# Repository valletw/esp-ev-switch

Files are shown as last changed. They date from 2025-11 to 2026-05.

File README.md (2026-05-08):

# ESP Electric Vehicle charge controller

The purpose of this project is to control a EVSE (Electric Vehicle Supply
Equipment), aka. "wall-box", to charge an electric vehicle. It will open/close
the Proximity Pilot (PP), the Control Pilot (CP) and the AC coil for the main
power. This project will not managed the EV protocol and be integrated only as a
switch between the vehicle and the EVSE. The control will be done with Home
Assistant by using [ESPHome](https://esphome.io) firmware.

Custom software could be written by using ESP-IDF SDK but it is not the purpose
of this project.

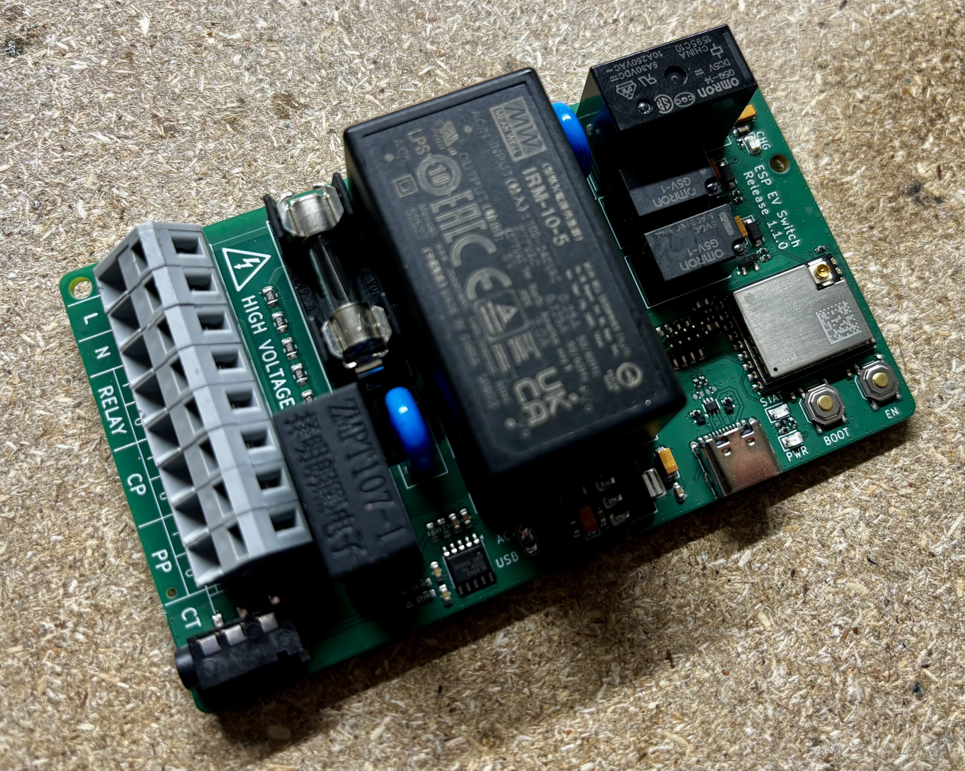
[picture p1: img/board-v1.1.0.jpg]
Board


## Signals description

**Proximity Pilot**, also known as "Plug Present", is used to signal the
connection / disconnection of the plug. It can be used to simulate a manual
disconnection by opening the circuit as the "release" button.

**Control Pilot** is used to negotiate the charge and exchange information by
the vehicle and the EVSE. In case of proximity pilot is not detected, the signal
can be opened to trigger an error on the charge controller.

**AC coil** is used to open/close the main power relay. In case of power is still
remaining after PP and CP are opened.

## Disclaimer

The authors and contributors of this repository disclaim any and all
responsibility for the misuse of the information, tools, or techniques described
herein. Users are strictly advised to utilize this information in accordance with
applicable laws and regulations and only on systems for which they have explicit
authorization.

Neither the authors nor contributors shall be held liable for any damages, direct
or indirect, resulting from the misuse or unauthorized application of the
knowledge contained herein.

These device is powered from 230V line. Every flash and debug steps shall be
take with extreme caution with main power supply disconnected or by using
an isolator on the USB connector !

## Hardware

Wago connector is used for easy plug with the different wall-box wires:

- `L`: Line (230V)
- `N`: Neutral
- `RELAY I/O`: EVSE main power supply coil control Input/Output
- `CP I/O`: EVSE Control Pilot Input/Output
- `PP I/O`: EVSE Proximity Pilot Input/Output

3.5mm jack is available for current transformer measure. It's compatible with the
sensor SCT-013-050. Different current limit could be selected depending of the
maximum voltage of your wall-box: for a 7kW charge, select at least a probe for
50 A.

Three status LED are available:

- `PWR`: 3.3V state
- `STAT`: System status controlled by software
- `CHG`: Charge indicator (all circuits are open/close)

Two buttons are available for ESP32 boot sequence:

- `BOOT`: Control processor download mode on boot
- `EN`: Control processor reset

For advanced debug, a 2x5 1.27 pins header connectors is available with the
Cortex-M JTAG/SWD pinout for external probe.

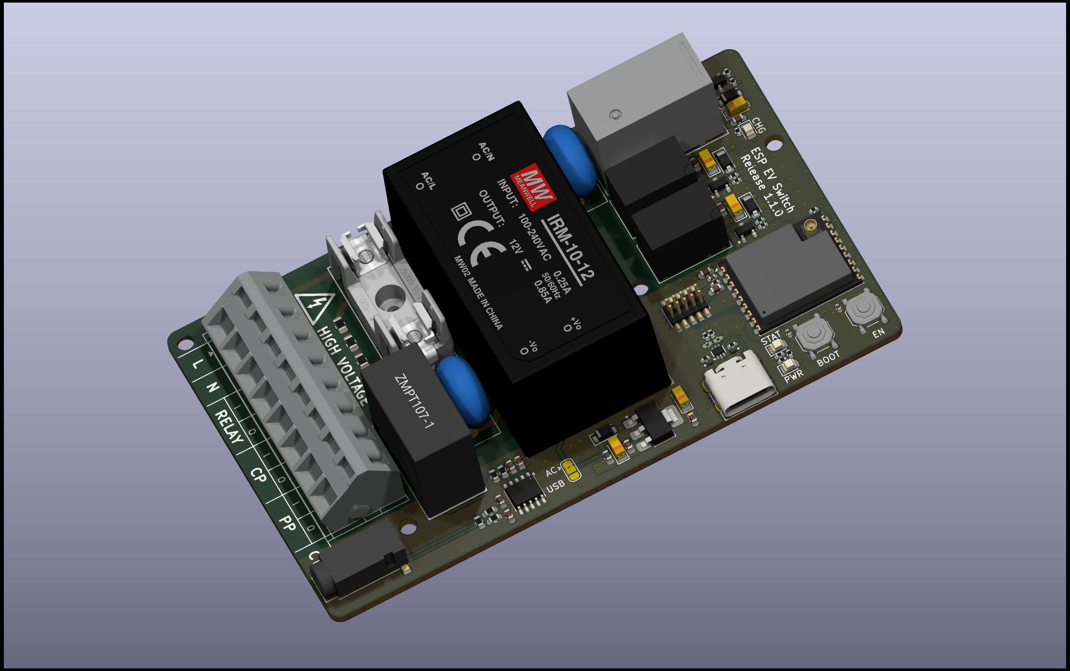
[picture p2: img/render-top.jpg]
Board top render

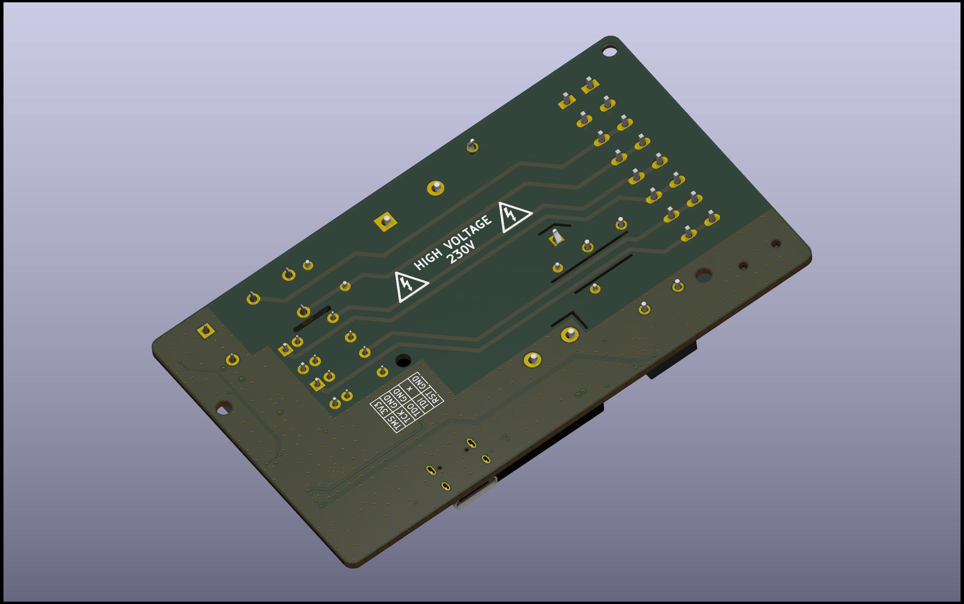
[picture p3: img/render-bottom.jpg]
Board bottom render


### Wiring

The board will be placed between the EVSE and the EV plug. It will open/close
the different signals to control the main power relay, the control signal and
the proximity signal.

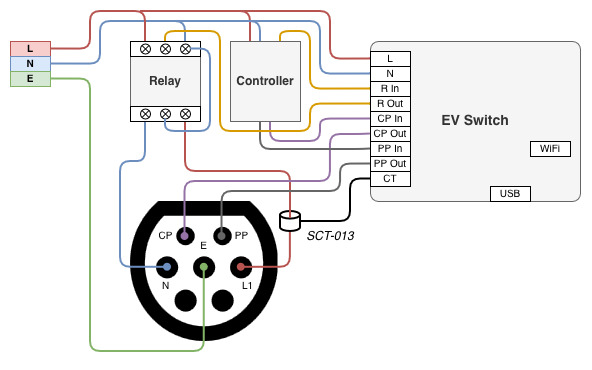
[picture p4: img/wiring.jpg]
EV Switch Wiring


Note: This wiring could be adapted for tri-phase system and should be able
to control the EVSE. The power measure can only be done on one phase.

You can see my setup on a QUBEV wallbox. The clamp take some space and I had to
put it on the input instead of the relay output because of the EV plug when I
closed the enclosure.

Also, the jack for the clamp broke when I installed the board, I was not careful
enough. As it's not through hole connector, it break easily. I added glue and a wire
as quick fix.

Setup | Home Assistant
:----:|:--------------:
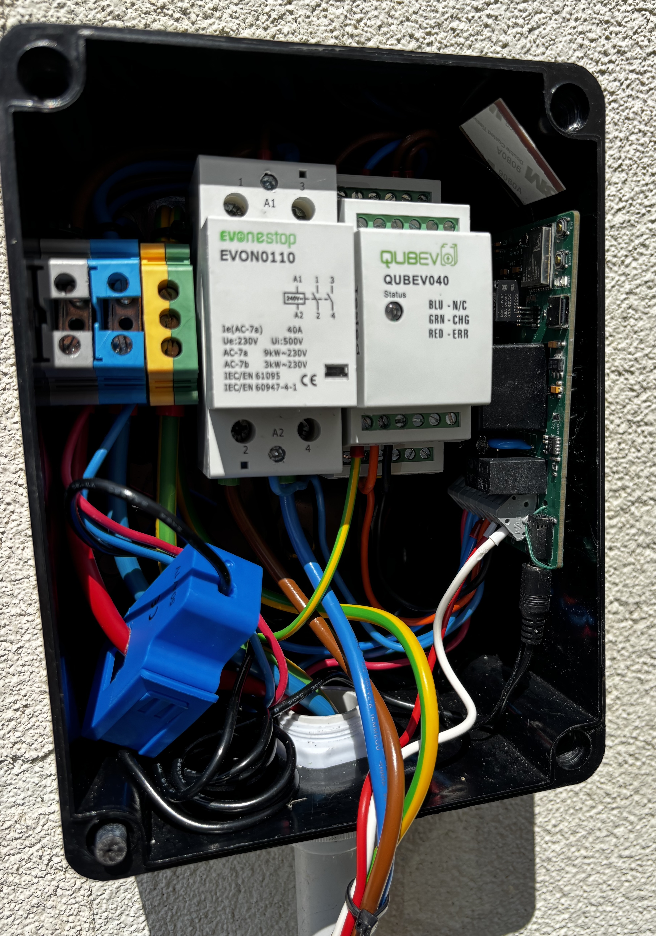
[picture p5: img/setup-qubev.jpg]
Setup on QUBEV
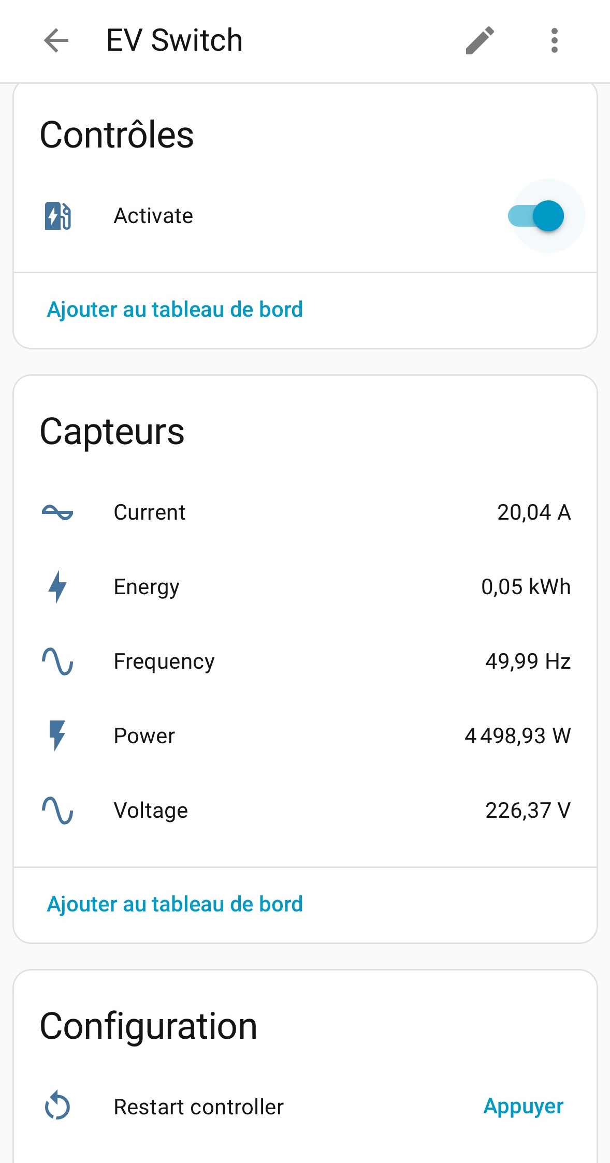
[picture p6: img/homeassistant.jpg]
Home Assistant Screenshot
 | 

Note: I limited my wallbox at 20A with an hardware switch inside.

### Components choice

This project is based on an ESP32-C3 module to simplify design and ensure good
WiFi performance (with external antenna connector). ESP32 has been selected for
the big community to generate software and the frameworks available. Espressif
hardware design rules has been take into account following there
[documentation](https://docs.espressif.com/projects/esp-hardware-design-guidelines/en/latest/esp32c3/pcb-layout-design.html)

For easy debug and flashing, ESP32 with USB-CDC and JTAG support has been selected.

The 5V power rail is generated from a Mean Well AC-DC power supply. It has been
selected for the "ready to use" and the security / certification. The 5V is used
to power the relays.
The 3.3V power rail is generated from a LDO using the 5V power rail. It's used for
the controller part: ESP32, measure and signals.

By default, the 5V from the USB connector is not connected. For debug, it can
be forced with a jumper to solder on the PCB. In this case, do not connect / solder
both 5V USB & 5V AC-DC.

All others components has been selected from [JLCPCB](https://jlcpcb.com/parts/)
catalogue to minimize the cost and the assembly fees.

### Manufacturing

The board is manufactured by [JLCPCB](https://jlcpcb.com), here is the details
you will require to generate an order.

*Note: JLCPCB requests some modifications on output files, do not use direct
export from KiCad (check the FAQ)*

#### PCB

Files: [Gerbers](jlcpcb/gerbers.zip)

Configuration              | Value
---------------------------|---------------------------------
Base Materiel              | FR-4
Layers                     | 4
Dimensions                 | 99.92 x 58.42 mm
Different design           | 1
Delivery format            | Single PCB
PCB thickness              | 1.6
PCB color                  | Green (other colors have fees)
Silkscreen                 | White
Materiel type              | FR4-Standard TG 135-140
Surface finish             | HASL
Specify layer sequence     | F_Cu / In1_Cu / In2_Cu / B_Cu
Impedance control          | Yes
Layer stack-up             | JLC04161H-7628
Via covering               | Tented
Min via hole size/diameter | 0.3mm/0.45mm
Remove order number        | Specify a location

*Note: All options have not been detail here, keep default value.*

#### Assembly

Files: [BOM](jlcpcb/bom.csv), [CPL](jlcpcb/cpl.csv)

Configuration       | Value
--------------------|--------------------
PCBA type           | Economic
Assembly side       | Top

Verify "pick & place" orientations and positions on the web viewer

*Note: All options have not been detail here, keep default value.*

### Calibration

For power consumption measurement, a BL0942 chip is used and connected to the
current transformer probe. Default values are set for the voltage, current, power
and energy reference. The BL0942 is calibration free and default value could
work. If better accuracy is required, the default value can be changed by following
a calibration process:

1. Voltage reference can be adapted by measuring the input voltage with a multimeter,
2. Current can be adapted by using a well known load: example 10 A,
3. When your voltage/current are correctly calibrated, the power can be computed
with `P = U * I`

#### Voltage reference

The voltage RMS is measured from VP/GND pins connected through a voltage transformer
for galvanic isolation. The primary side uses a resistive divider 235 kOhms (5 * 47k)
to limit the current through the transformer primary. On the secondary side, a 56 Ohms
resistor sets the output voltage, followed by a 1 kOhms series resistor on the VP pin
for protection.

The transformer is designed as a current source: the primary voltage drives a current
through R_in, which is then converted back to a voltage across R_out on the secondary:

```math
U_{out} = \frac{U_{in}}{R_{in}} \times R_{out}
```

```math
U_{out} = \frac{230}{235000} \times 56 = 54.8 mV
```

The BL0942 VP input full-scale is 70 mV RMS / 100 mV peak-to-peak. The operating
points relative to full-scale are:

Input voltage | VP voltage | % of full-scale
:------------:|:----------:|:---------------:
230 V         | 54.8 mV    | 78 %
260 V         | 61.9 mV    | 88 %

From the datasheet, the internal register value is computed with the following formula:

```math
V_{RMS} = \frac{73989 \times V(mV)}{V_{ref}}
```

```math
V_{ref} = 1.218 V
```

With the previous values (expected VP voltage and chip reference voltage) we can
estimate the voltage reference for the ESPHome configuration:

```math
Reference = \frac{V_{RMS}}{V_{in}}
```

```math
Reference = \frac{\frac{73989 \times 54.8}{1.218}}{230} = 14477
```

After test on the received board, the measured voltage reference is **14400**,
consistent with the theoretical value (< 0.5 % deviation). This value will be used
as a base to improve accuracy by adjusting it while measuring the input voltage with
a calibrated True RMS multimeter.

#### Current reference

The current RMS is measured from IP/IN pins connected to a `SCT-013-050` current
transformer clamp through a signal conditioning circuit.

##### SCT-013-050 model

The `SCT-013-050` is a voltage output clamp with a built-in burden resistor `Rb`.
It is designed as a current source with the following characteristics:

Parameter       | Value
----------------|-------------------------------
Rated input     | 50 A RMS
Rated output    | 1 V RMS
Internal burden | Rb = ~37 Ohms
Turns ratio     | N = 50 / (1V / 37 Ohms) = 1850
Sensitivity     | 20 mV/A RMS

The secondary current for a given primary current is:

```math
I_s = \frac{I_{in}}{N} = \frac{I_{in}}{1850}
```

##### Signal conditioning circuit

The IP/IN pins are connected as follows:

- 1 Ohms (`R201`) in parallel with CT_K/CT_L (external burden)
- 1 kOhms in series on each line (pin protection)

`R201` forms a parallel combination with `Rb`, reducing the effective burden:

```math
R_{burden} = \frac{Rb \times R201}{Rb + R201} = \frac{37 \times 1}{37 + 1} = 0.974 Ω
```

The differential voltage on IP/IN for a given primary current is:

```math
U_{out} = \frac{I_{in}}{N} \times R_{burden} = \frac{I_{in}}{1850} \times 0.974
```

The BL0942 IP/IN full-scale is 30 mV RMS / 42 mV peak-to-peak. The operating
points relative to full-scale are:

Primary current | IP/IN voltage | % of full-scale
:--------------:|:-------------:|:---------------:
50 A            | 26 mV         | 90 %
32 A            | 17 mV         | 57 %
16 A            | 8 mV          | 27 %
2 A             | 1 mV          | 3 %

##### Current reference calculation

From the datasheet, the internal register value is computed with the following formula:

```math
I_{RMS} = \frac{305978 \times U_{out}(mV)}{V_{ref}}
```

```math
V_{ref} = 1.218 V
```

With the previous values we can estimated the current reference for the ESPHome
configuration:

```math
Reference = \frac{I_{RMS}}{I_{in}} = \frac{305978 \times R_{burden}}{V_{ref} \times N}
```

```math
Reference = \frac{305978 \times 974}{1.218 \times 1850} = 132260
```

After test on the received board, the measured current reference is **119500**,
representing a ~10 % deviation from the theoretical value, consistent with the
combined tolerances of `Rb` (10 %), `R201` (1 %), and the BL0942 internal reference.
This value will be used as a base to improve accuracy by adjusting it while
measuring the input current with a calibrated True RMS clamp meter.

### ESP32 Pinout

For those who want to reuse this project, here is the ESP32 pinout to manage the
different input/output.

Name               | Pin  | Direction
-------------------|------|----------
Relay ON           | IO0  | Output
Control Pilot ON   | IO1  | Output
Charge LED         | IO2  | Output (strapping pin)
Proximity Pilot ON | IO3  | Output
System Status LED  | IO8  | Output (strapping pin)
BL0942 CF1         | IO10 | Input
BL0942 Tx          | RX   | Input
BL0942 Rx          | TX   | Output

## ESPHome configuration

Device must be setup via USB connection the first time to flash the customized
firmware with sensors/buttons configuration.

Once it has been configured successfully, you should fix the device IP on your
router for easier Home Assistant configuration.

Note: Installation can be bypassed if already done or you can use docker image.
Check [ESPHome documentation](https://esphome.io/guides/getting_started_command_line.html)
for more details.

### Installation

```shell
pip install esphome
# Ensure your user session has the correct permission for serial port.
sudo usermod -a -G dialout <USERNAME>
```

### Customize

Depending of your installation and network, a `secrets.yaml` file must be
create with your specific configuration.

```yaml
# secrets.yaml
wifi_ssid: MySSID
wifi_password: MyStrongPassphrase
wifi_fb_ssid: ATX Controller Fallback Hotspot
wifi_fb_password: StrongPassphrase
ota_password: MyOTAPassphrase
api_key: 32BytesBase64String
```

### Compile and flash

```shell
# Generate the firmware.
esphome compile esphome.yaml
# Flash the firmware to the ESP.
esphome run esphome.yaml
# Get logs.
esphome logs esphome.yaml
```

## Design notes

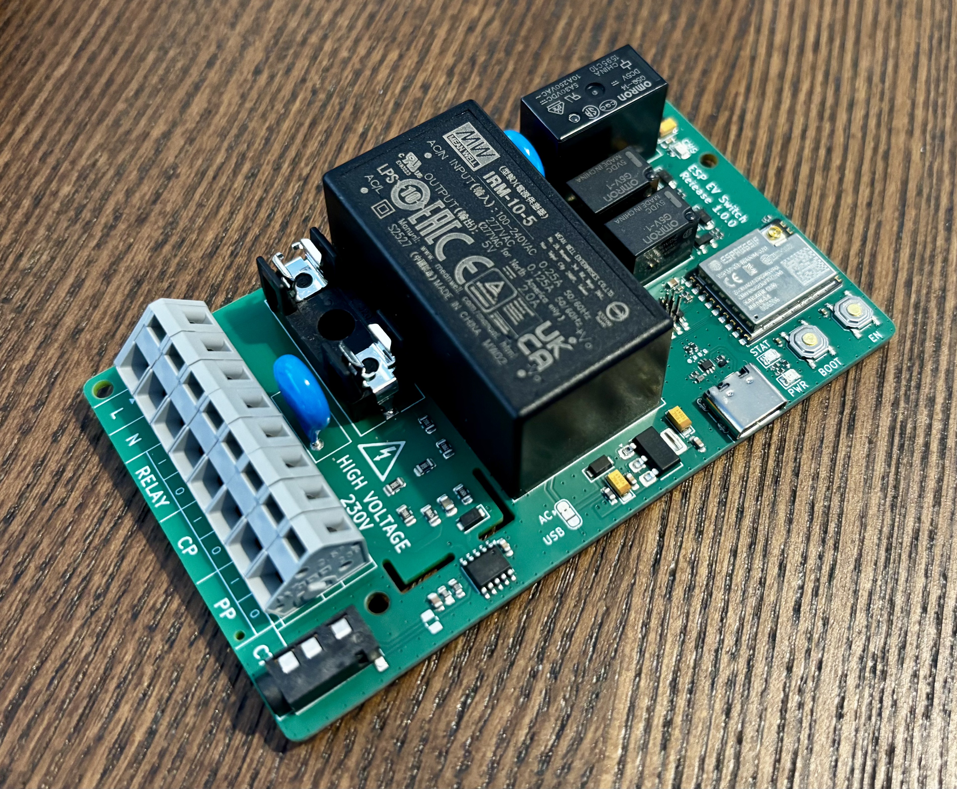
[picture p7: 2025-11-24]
img/board-v1.0.0.jpg

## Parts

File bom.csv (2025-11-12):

Reference | Value | Qty | Footprint | LCSC Part # | MFR Part # | Manufacturer | Datasheet
C101,C102,C108 | 100n | 3 | Capacitor_SMD:C_0402_1005Metric | C1525 | CL05B104KO5NNNC | Samsung Electro-Mechanics | https://datasheet.lcsc.com/lcsc/2304140030_Samsung-Electro-Mechanics-CL05B104KO5NNNC_C1525.pdf
C103,C105,C201,C204,C208 | 10u | 5 | Capacitor_Tantalum_SMD:CP_EIA-3216-18_Kemet-A | C7171 | TAJA106K016RNJ
C104,C106,C202,C205,C206,C209 | 100n | 6 | Capacitor_SMD:C_0603_1608Metric | C14663 | CC0603KRX7R9BB104 | YAGEO | https://jlcpcb.com/api/file/downloadByFileSystemAccessId/8579707083955945472
C107,C203 | 10u | 2 | Capacitor_SMD:C_0603_1608Metric | C96446 | CL10A106MA8NRNC | Samsung Electro-Mechanics | https://datasheet.lcsc.com/lcsc/2208231630_Samsung-Electro-Mechanics-CL05A106MQ5NUNC_C15525.pdf
C109 | 1u | 1 | Capacitor_SMD:C_0402_1005Metric | C52923 | CL05A105KA5NQNC | Samsung Electro-Mechanics | https://datasheet.lcsc.com/lcsc/2304140030_Samsung-Electro-Mechanics-CL05A105KA5NQNC_C52923.pdf
C110,C111 | ~ | 2 | Capacitor_SMD:C_0402_1005Metric
C207 | 100n | 1 | Capacitor_SMD:C_0805_2012Metric | C49678 | CC0805KRX7R9BB104 | YAGEO | https://jlcpcb.com/api/file/downloadByFileSystemAccessId/8579706882463744000
D101,D106 | Red | 2 | LED_SMD:LED_0805_2012Metric | C84256 | NCD0805R1 | Foshan NationStar Optoelectronics | https://jlcpcb.com/api/file/downloadByFileSystemAccessId/8550724080677908480
D102 | Green | 1 | LED_SMD:LED_0805_2012Metric | C2297 | KT-0805G | Hubei KENTO Elec | https://jlcpcb.com/api/file/downloadByFileSystemAccessId/8639582106239348736
D103,D203 | SMF5.0A | 2 | Diode_SMD:D_SOD-123F | C19077497 | SMF5.0A | hongjiacheng | https://jlcpcb.com/api/file/downloadByFileSystemAccessId/8564880887079854080
D104,D105 | TPD1E05U06 | 2 | Package_SON:Texas_DPY0002A_0.6x1mm_P0.65mm | C436349 | TPD1E05U06DPYR | Texas Instruments | https://www.ti.com/lit/ds/symlink/tpd4e05u06.pdf
D201 | 1N4007 | 1 | Diode_SMD:D_SOD-123F | C18199088 | 1N4007W | hongjiacheng | http://www.vishay.com/docs/88503/1n4001.pdf
D202,D204 | 1N4148W | 2 | Diode_SMD:D_SOD-123 | C7420318 | 1N4148W | hongjiacheng | https://jlcpcb.com/api/file/downloadByFileSystemAccessId/8590903824854953984
F101 | 5x20 250mA | 1 | footprints:Littelfuse_05200101Z | C142924 | 05200101Z | Littelfuse | https://jlcpcb.com/api/file/downloadByFileSystemAccessId/8589838583365197824
J101 | Screw_Terminal_01x08 | 1 | TerminalBlock_WAGO:TerminalBlock_WAGO_236-408_1x08_P5.00mm_45Degree | C3820284 | 236-408 | WAGO | https://jlcpcb.com/api/file/downloadByFileSystemAccessId/8590242270546337792
J102 | AudioJack3 | 1 | Connector_Audio:Jack_3.5mm_PJ320D_Horizontal | C431535 | PJ-320D | SHOU HAN | https://jlcpcb.com/api/file/downloadByFileSystemAccessId/8588894189044314112
J103 | GT-USB-7010ASV | 1 | Connector_USB:USB_C_Receptacle_G-Switch_GT-USB-7010ASV | C2988369 | GT-USB-7010ASV | G-Switch | https://datasheet.lcsc.com/lcsc/2303271630_G-Switch-GT-USB-7010ASV_C2988369.pdf
J104 | Conn_ARM_JTAG_SWD_10 | 1 | Connector_PinHeader_1.27mm:PinHeader_2x05_P1.27mm_Vertical_SMD | C41376037 | HX PZ1.27-2x5P TP | hanxia | http://infocenter.arm.com/help/topic/com.arm.doc.ddi0314h/DDI0314H_coresight_components_trm.pdf
JP101 | SolderJumper_3_Bridged12 | 1 | Jumper:SolderJumper-3_P1.3mm_Bridged2Bar12_RoundedPad1.0x1.5mm |  |  |  | ~
K201 | G5Q-14 | 1 | Relay_THT:Relay_SPDT_Omron-G5Q-1 | C397241 | G5Q-14 DC5 | Omron Electronics | https://www.omron.com/ecb/products/pdf/en-g5q.pdf
K202,K203 | G5V-1 | 2 | Relay_THT:Relay_SPDT_Omron_G5V-1 | C28695 | G5V-1 DC5 | Omron Electronics | http://omronfs.omron.com/en_US/ecb/products/pdf/en-g5v_1.pdf
L101 | Ferrite Bead | 1 | Inductor_SMD:L_0603_1608Metric | C14709 | BLM18PG121SN1D | Murata Electronics | https://jlcpcb.com/api/file/downloadByFileSystemAccessId/8588900229559300096
MH101,MH102,MH103,MH104 | ~ | 4 | MountingHole:MountingHole_2.7mm_M2.5_ISO7380 |  |  |  | ~
PS101 | IRM-10-5 | 1 | Converter_ACDC:Converter_ACDC_MeanWell_IRM-10-xx_THT | C2857903 | IRM-10-5 | MW(MEAN WELL Enterprises) | https://www.meanwell.com/Upload/PDF/IRM-10/IRM-10-SPEC.PDF
Q201,Q202,Q203 | SS8050 | 3 | Package_TO_SOT_SMD:SOT-23 | C2150 | SS8050(RANGE:200-350) | Jiangsu Changjing Electronics Technology Co., Ltd. | http://www.secosgmbh.com/datasheet/products/SSMPTransistor/SOT-23/SS8050.pdf
R101,R102,R110 | 1.2k | 3 | Resistor_SMD:R_0402_1005Metric | C25862 | 0402WGF1201TCE | UNI-ROYAL(Uniroyal Elec) | https://jlcpcb.com/api/file/downloadByFileSystemAccessId/8579706055238078464
R103,R106,R107 | 10k | 3 | Resistor_SMD:R_0402_1005Metric | C25744 | 0402WGF1002TCE | UNI-ROYAL(Uniroyal Elec) | https://datasheet.lcsc.com/lcsc/2206010100_UNI-ROYAL-Uniroyal-Elec-0402WGF1002TCE_C25744.pdf
R104,R105 | 5.1k | 2 | Resistor_SMD:R_0402_1005Metric | C25905 | 0402WGF5101TCE | UNI-ROYAL(Uniroyal Elec) | https://datasheet.lcsc.com/lcsc/2206010045_UNI-ROYAL-Uniroyal-Elec-0402WGF5101TCE_C25905.pdf
R108,R109 | 22 | 2 | Resistor_SMD:R_0402_1005Metric | C25092 | 0402WGF220JTCE | UNI-ROYAL(Uniroyal Elec) | https://jlcpcb.com/api/file/downloadByFileSystemAccessId/8579705904671227904
R201 | 33 | 1 | Resistor_SMD:R_0805_2012Metric | C17634 | 0805W8F330JT5E | UNI-ROYAL(Uniroyal Elec) | https://jlcpcb.com/api/file/downloadByFileSystemAccessId/8579706226143518720
R202,R204 | 100k | 2 | Resistor_SMD:R_0603_1608Metric | C25803 | 0603WAF1003T5E | UNI-ROYAL(Uniroyal Elec) | https://jlcpcb.com/api/file/downloadByFileSystemAccessId/8579706350726930432
R203,R209,R215 | 330 | 3 | Resistor_SMD:R_0402_1005Metric | C25104 | 0402WGF3300TCE | UNI-ROYAL(Uniroyal Elec) | https://jlcpcb.com/api/file/downloadByFileSystemAccessId/8579706350726930432
R205,R210,R216 | 100k | 3 | Resistor_SMD:R_0402_1005Metric | C25741 | 0402WGF1003TCE | UNI-ROYAL(Uniroyal Elec) | https://jlcpcb.com/api/file/downloadByFileSystemAccessId/8579706350726930432
R206,R207,R208,R211,R212 | 200k | 5 | Resistor_SMD:R_0805_2012Metric | C17539 | 0805W8F2003T5E | UNI-ROYAL(Uniroyal Elec) | https://jlcpcb.com/api/file/downloadByFileSystemAccessId/8579706517206974464
R213 | 1k | 1 | Resistor_SMD:R_0805_2012Metric | C17513 | 0805W8F1001T5E | UNI-ROYAL(Uniroyal Elec) | https://jlcpcb.com/api/file/downloadByFileSystemAccessId/8579706499683172352
R214 | 470 | 1 | Resistor_SMD:R_0805_2012Metric | C17710 | 0805W8F4700T5E | UNI-ROYAL(Uniroyal Elec) | https://jlcpcb.com/api/file/downloadByFileSystemAccessId/8579706597980880896
RV101,RV201 | 275VAC | 2 | Varistor:RV_Disc_D12mm_W5.4mm_P7.5mm | C8760 | 10D471K | RUILON(Shenzhen Ruilongyuan Elec) | https://jlcpcb.com/api/file/downloadByFileSystemAccessId/8588887227166298112
SW101,SW102 | TS-1187A-B-A-B | 2 | Button_Switch_SMD:SW_Push_1P1T_XKB_TS-1187A | C318884 | TS-1187A-B-A-B | XKB Connectivity | https://datasheet.lcsc.com/lcsc/2304140030_XKB-Connectivity-TS-1187A-B-A-B_C318884.pdf
U101 | AMS1117-3.3 | 1 | Package_TO_SOT_SMD:SOT-223-3_TabPin2 | C6186 | AMS1117-3.3 | Advanced Monolithic Systems | http://www.advanced-monolithic.com/pdf/ds1117.pdf
U102 | USBLC6-2P6 | 1 | Package_TO_SOT_SMD:SOT-666 | C15999 | USBLC6-2P6 | STMicroeletronics | https://www.st.com/resource/en/datasheet/usblc6-2.pdf
U103 | ESP32-C3-WROOM-02U | 1 | RF_Module:ESP32-C3-WROOM-02U | C2926676 | ESP32-C3-WROOM-02U-N4 | Espressif Systems | https://www.espressif.com/sites/default/files/documentation/esp32-c3-wroom-02_datasheet_en.pdf
U201 | BL0942 | 1 | Package_SO:SSOP-10_3.9x4.9mm_P1.00mm | C2837510 | BL0942 | Belling | https://www.belling.com.cn/media/file_object/bel_product_en/BL0942/datasheet/BL0942_V1.04_en.pdf

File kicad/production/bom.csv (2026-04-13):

Designator | Footprint | Quantity | Value | LCSC Part #
C101, C102, C108 | 0402 | 3 | 100n | C1525
C103, C105, C201, C204, C208 | CP_EIA-3216-18_Kemet-A | 5 | 10u | C7171
C104, C106, C202, C205, C206, C209 | 0603 | 6 | 100n | C14663
C107, C109 | 0603 | 2 | 10u | C96446
C203, C207, C210 | 0603 | 3 | 33n | C21117
D101, D106 | 0805 | 2 | Red | C84256
D102 | 0805 | 1 | Green | C2297
D103 | D_SOD-123F | 1 | SMF5.0A | C19077497
D104, D105 | Texas_DPY0002A_0.6x1mm_P0.65mm | 2 | TPD1E05U06 | C436349
D201 | D_SOD-123F | 1 | 1N4007 | C18199088
D202, D204 | D_SOD-123 | 2 | 1N4148W | C7420318
F101 | Littelfuse_05200101Z | 1 | 5x20 250mA | C142924
J101 | TerminalBlock_WAGO_236-408_1x08_P5.00mm_45Degree | 1 | Screw_Terminal_01x08 | C3820284
J102 | Jack_3.5mm_PJ320D_Horizontal | 1 | AudioJack3 | C431535
J103 | USB_C_Receptacle_G-Switch_GT-USB-7010ASV | 1 | GT-USB-7010ASV | C2988369
J104 | PinHeader_2x05_P1.27mm_Vertical_SMD | 1 | Conn_ARM_JTAG_SWD_10 | C41376037
K201 | Relay_SPDT_Omron-G5Q-1 | 1 | G5Q-14 | C397241
K202, K203 | Relay_SPDT_Omron_G5V-1 | 2 | G5V-1 | C28695
L101 | 0603 | 1 | Ferrite Bead | C14709
PS101 | Converter_ACDC_MeanWell_IRM-10-xx_THT | 1 | IRM-10-5 | C2857903
Q201, Q202, Q203 | SOT-23 | 3 | SS8050 | C2150
R101, R102, R110 | 0402 | 3 | 1.2k | C25862
R103, R106, R107 | 0402 | 3 | 10k | C25744
R104, R105 | 0402 | 2 | 5.1k | C25905
R108, R109 | 0402 | 2 | 22 | C25092
R201 | 0603 | 1 | 1 | C22936
R202, R204, R213 | 0603 | 3 | 1k | C21190
R203, R209, R215 | 0402 | 3 | 330 | C25104
R205, R210, R216 | 0402 | 3 | 100k | C25741
R206, R207, R208, R211, R212 | 0805 | 5 | 47k | C17713
R214 | 0603 | 1 | 56 | C25196
RV101, RV201 | RV_Disc_D12mm_W5.4mm_P7.5mm | 2 | 275VAC | C8760
SW101, SW102 | SW_Push_1P1T_XKB_TS-1187A | 2 | TS-1187A-B-A-B | C318884
TR201 | XFMR-TH_ZMPT107-1 | 1 | ZMPT107-1 | C125191
U101 | SOT-223-3_TabPin2 | 1 | AMS1117-3.3 | C6186
U102 | SOT-666 | 1 | USBLC6-2P6 | C15999
U103 | ESP32-C3-WROOM-02U | 1 | ESP32-C3-WROOM-02U | C2926676
U201 | SSOP-10_3.9x4.9mm_P1.00mm | 1 | BL0942 | C2837510

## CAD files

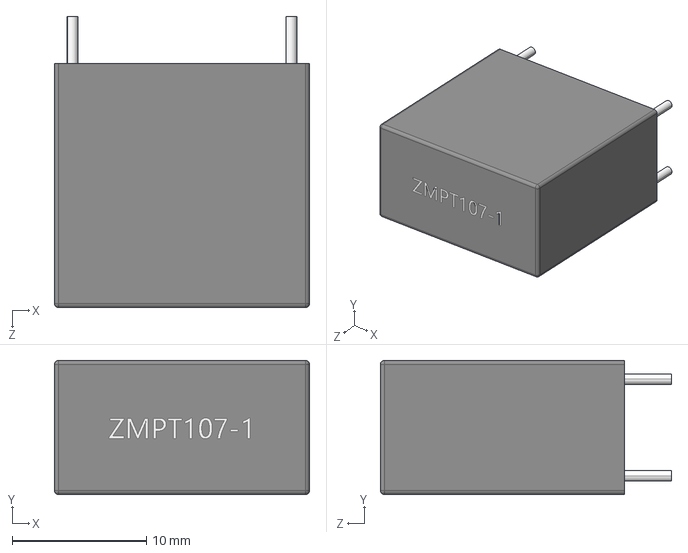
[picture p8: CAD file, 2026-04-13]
librairies/3dmodels/XFMR-TH_L19.0-W10.0-H18.2.step
19.0 x 10.0 x 21.7 mm

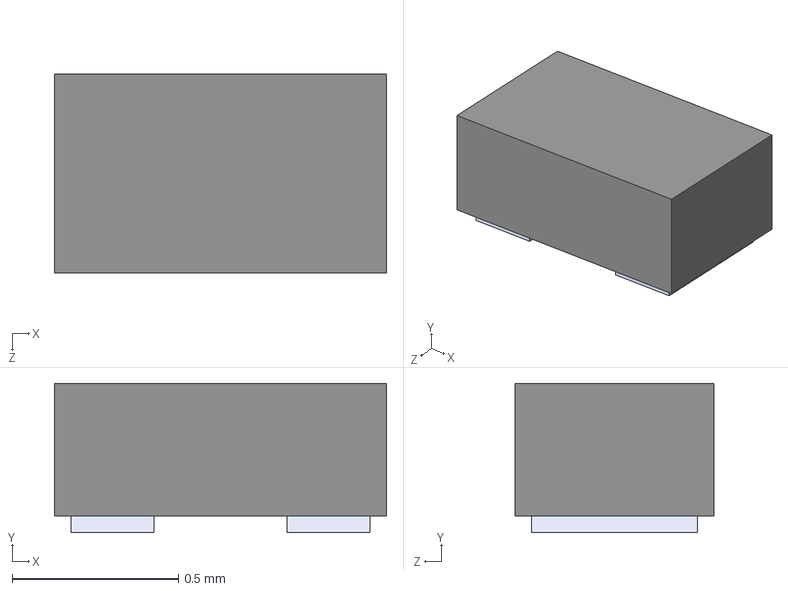
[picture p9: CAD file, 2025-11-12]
librairies/3dmodels/TPD1E05U06DPYR.step
1.00 x 0.45 x 0.6 mm

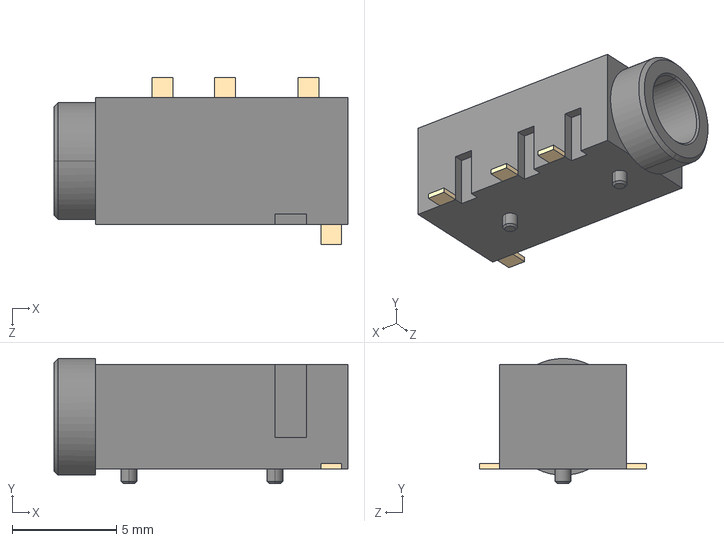
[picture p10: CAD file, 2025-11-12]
librairies/3dmodels/PJ-320D-A.step
14.1 x 6.00 x 8.00 mm

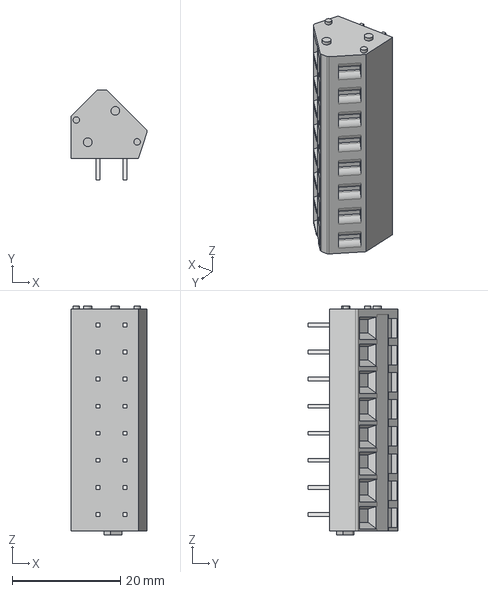
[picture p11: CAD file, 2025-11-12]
librairies/3dmodels/WAGO_236-408.stp
14.1 x 16.7 x 42.3 mm

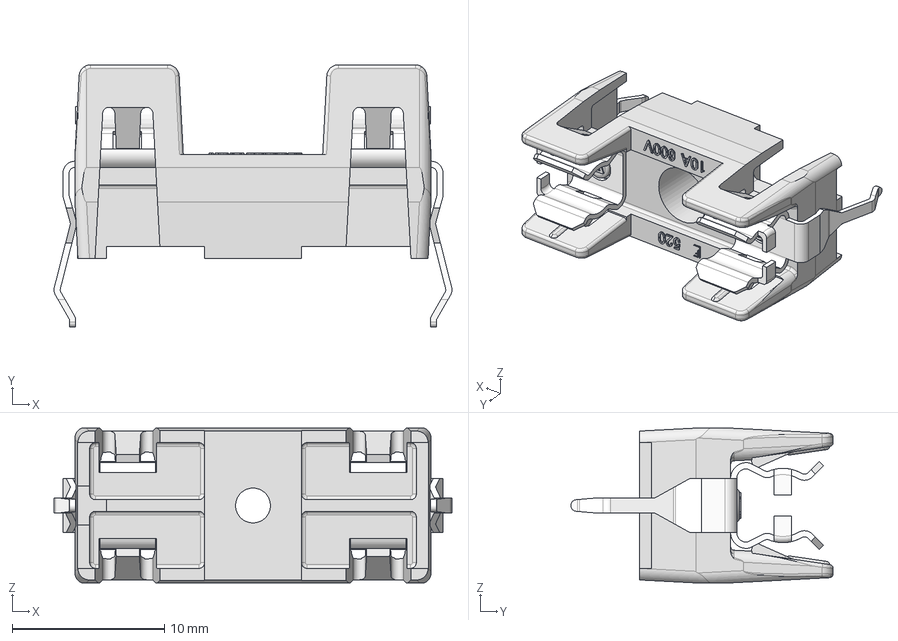
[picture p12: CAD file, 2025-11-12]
librairies/3dmodels/Littelfuse_05200101Z.stp
26.1 x 17.2 x 10.2 mm
111509_MIR

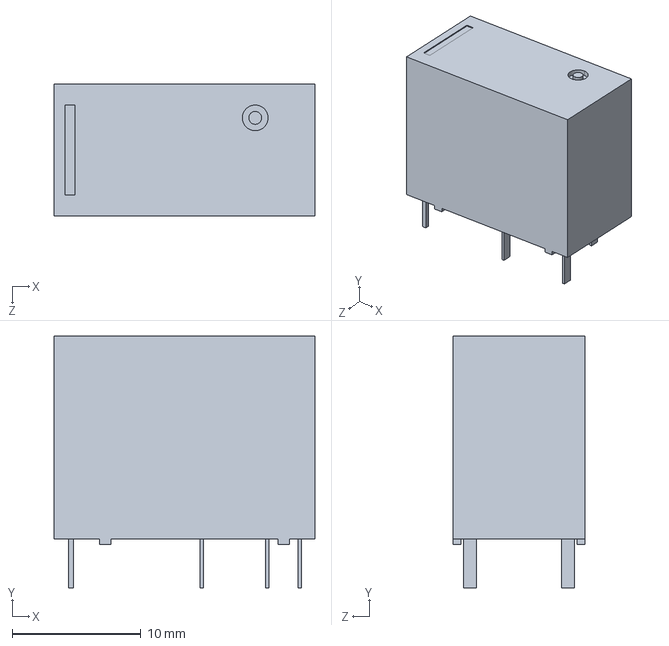
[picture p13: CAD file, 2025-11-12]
librairies/3dmodels/G5Q-14_DC5.step
20.3 x 19.6 x 10.3 mm

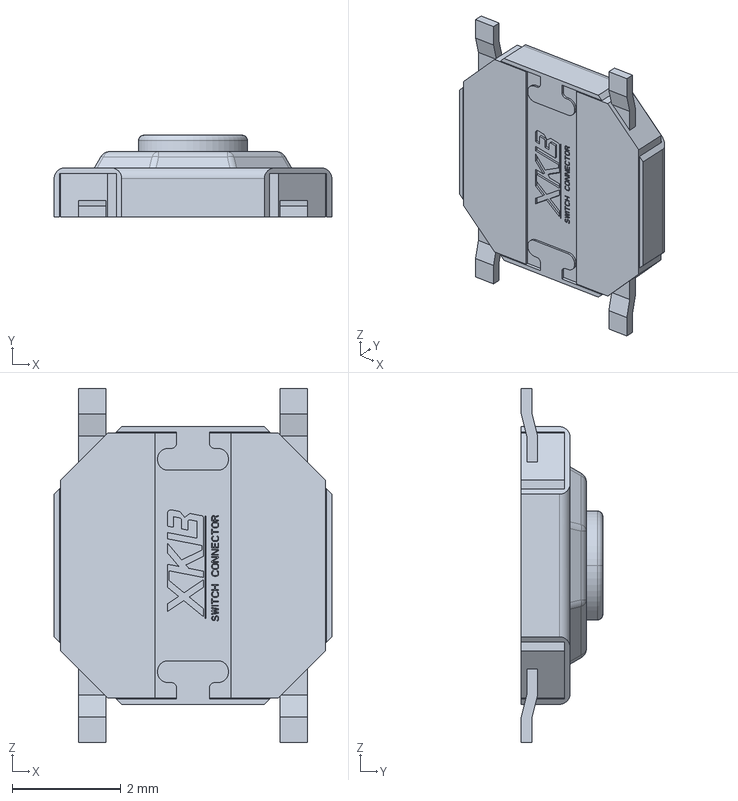
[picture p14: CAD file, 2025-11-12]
librairies/3dmodels/TS-1187A-B-A-B.stp
5.10 x 1.50 x 6.50 mm

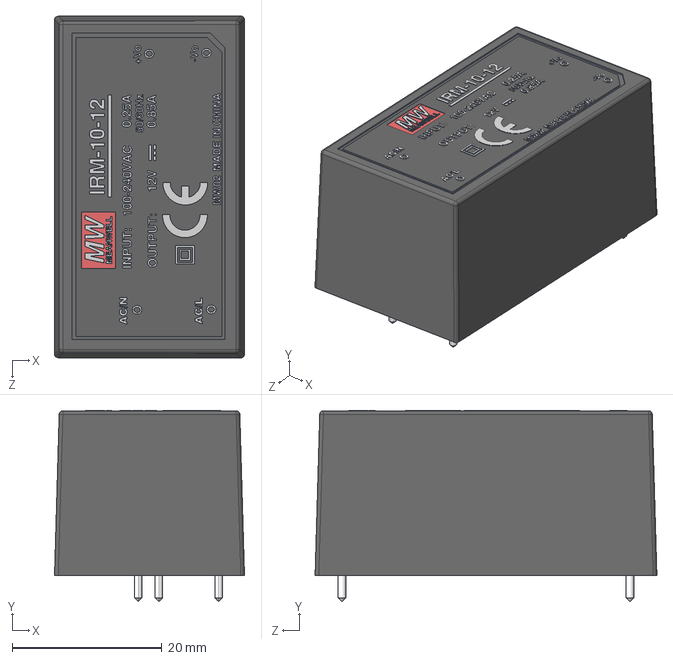
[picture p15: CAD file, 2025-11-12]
librairies/3dmodels/IRM-10-5.stp
25.4 x 25.6 x 45.7 mm

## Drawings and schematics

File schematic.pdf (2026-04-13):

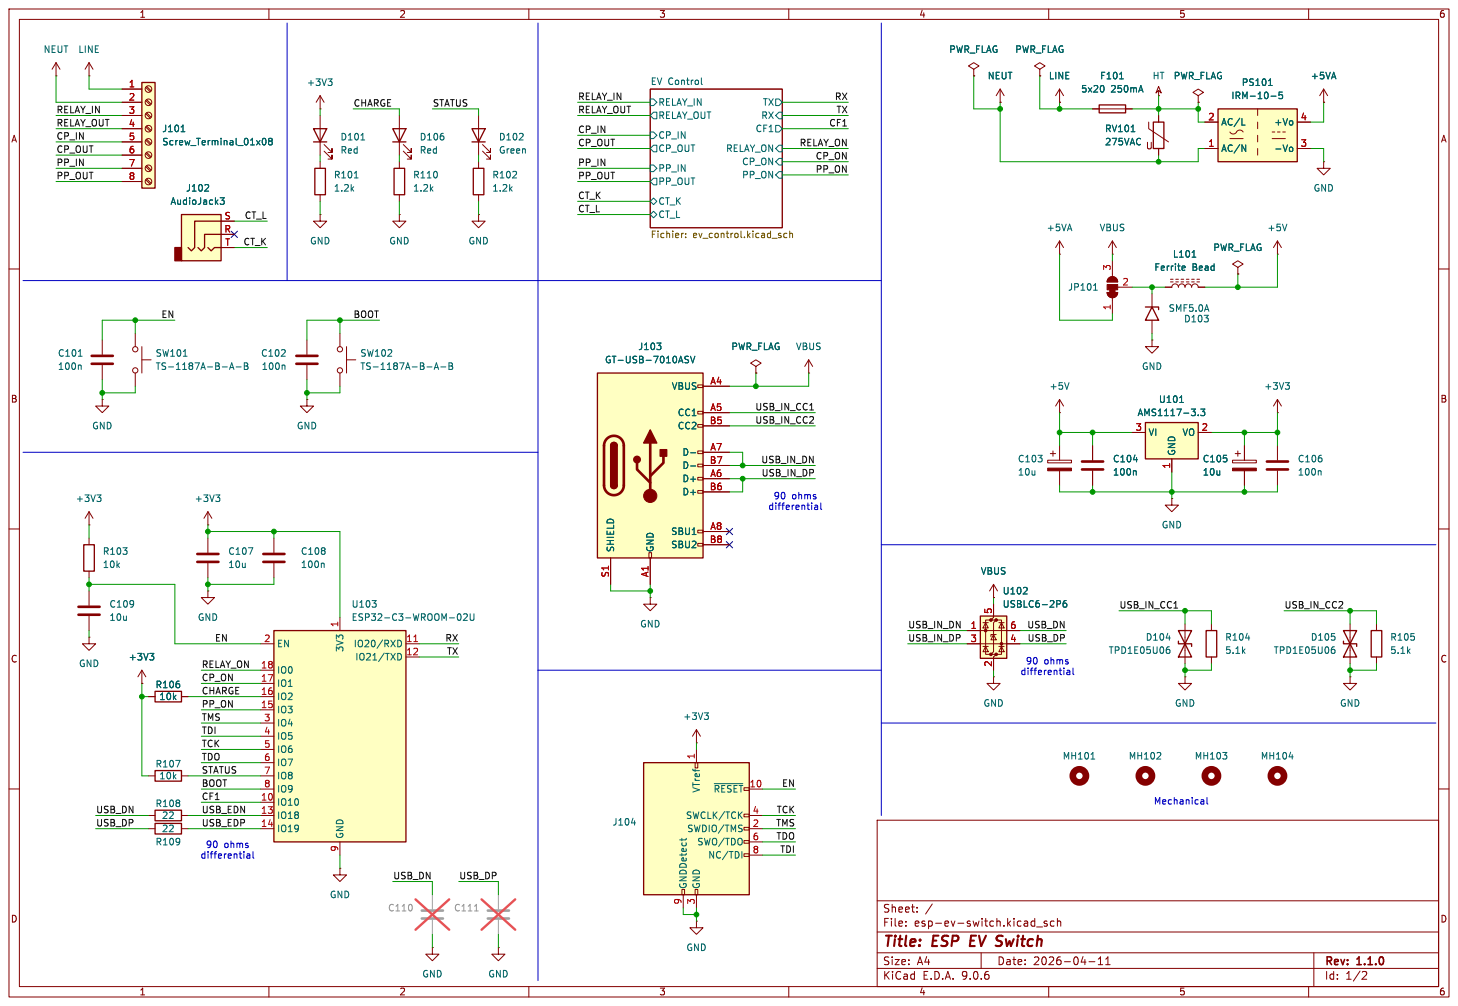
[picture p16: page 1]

3 ~{RESET}10 SWCLK/TCK 4 SWDIO/TMS 2 SWO/TDO 6 NC/TDI 8

File: esp-ev-switch.kicad_sch Sheet: /
Id: 1/2 Title: ESP EV Switch

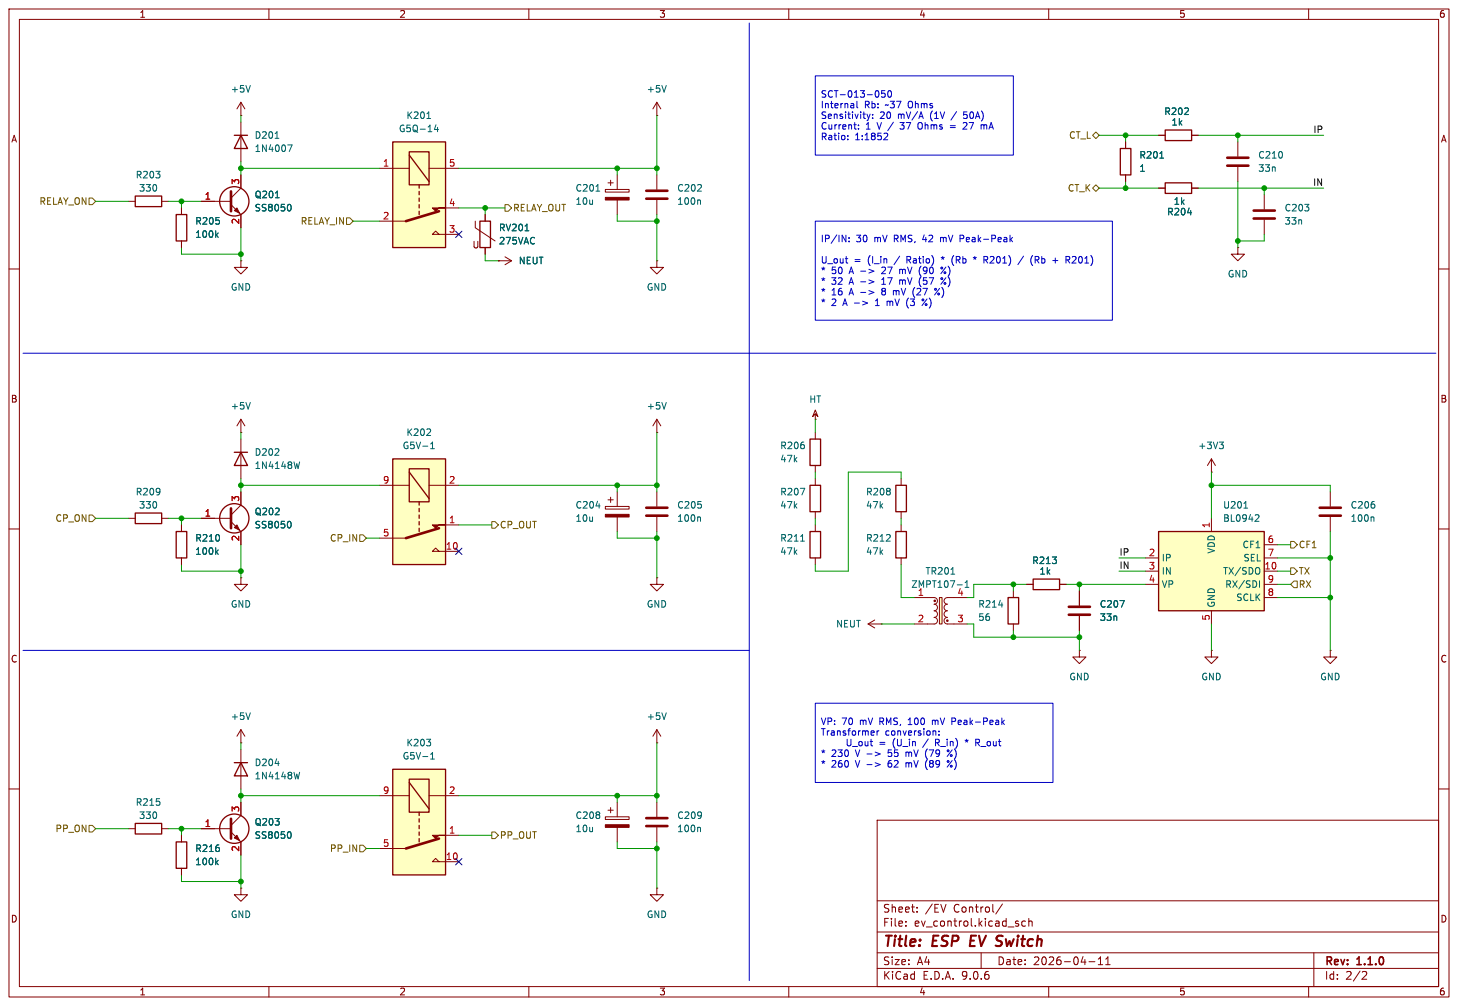
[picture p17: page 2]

5 CF1 6 SEL 7 TX/SDO 10 RX/SDI 9 SCLK 8 U201 BL0942 NEUT R214

File: ev_control.kicad_sch Sheet: /EV Control/
Id: 2/2 Title: ESP EV Switch

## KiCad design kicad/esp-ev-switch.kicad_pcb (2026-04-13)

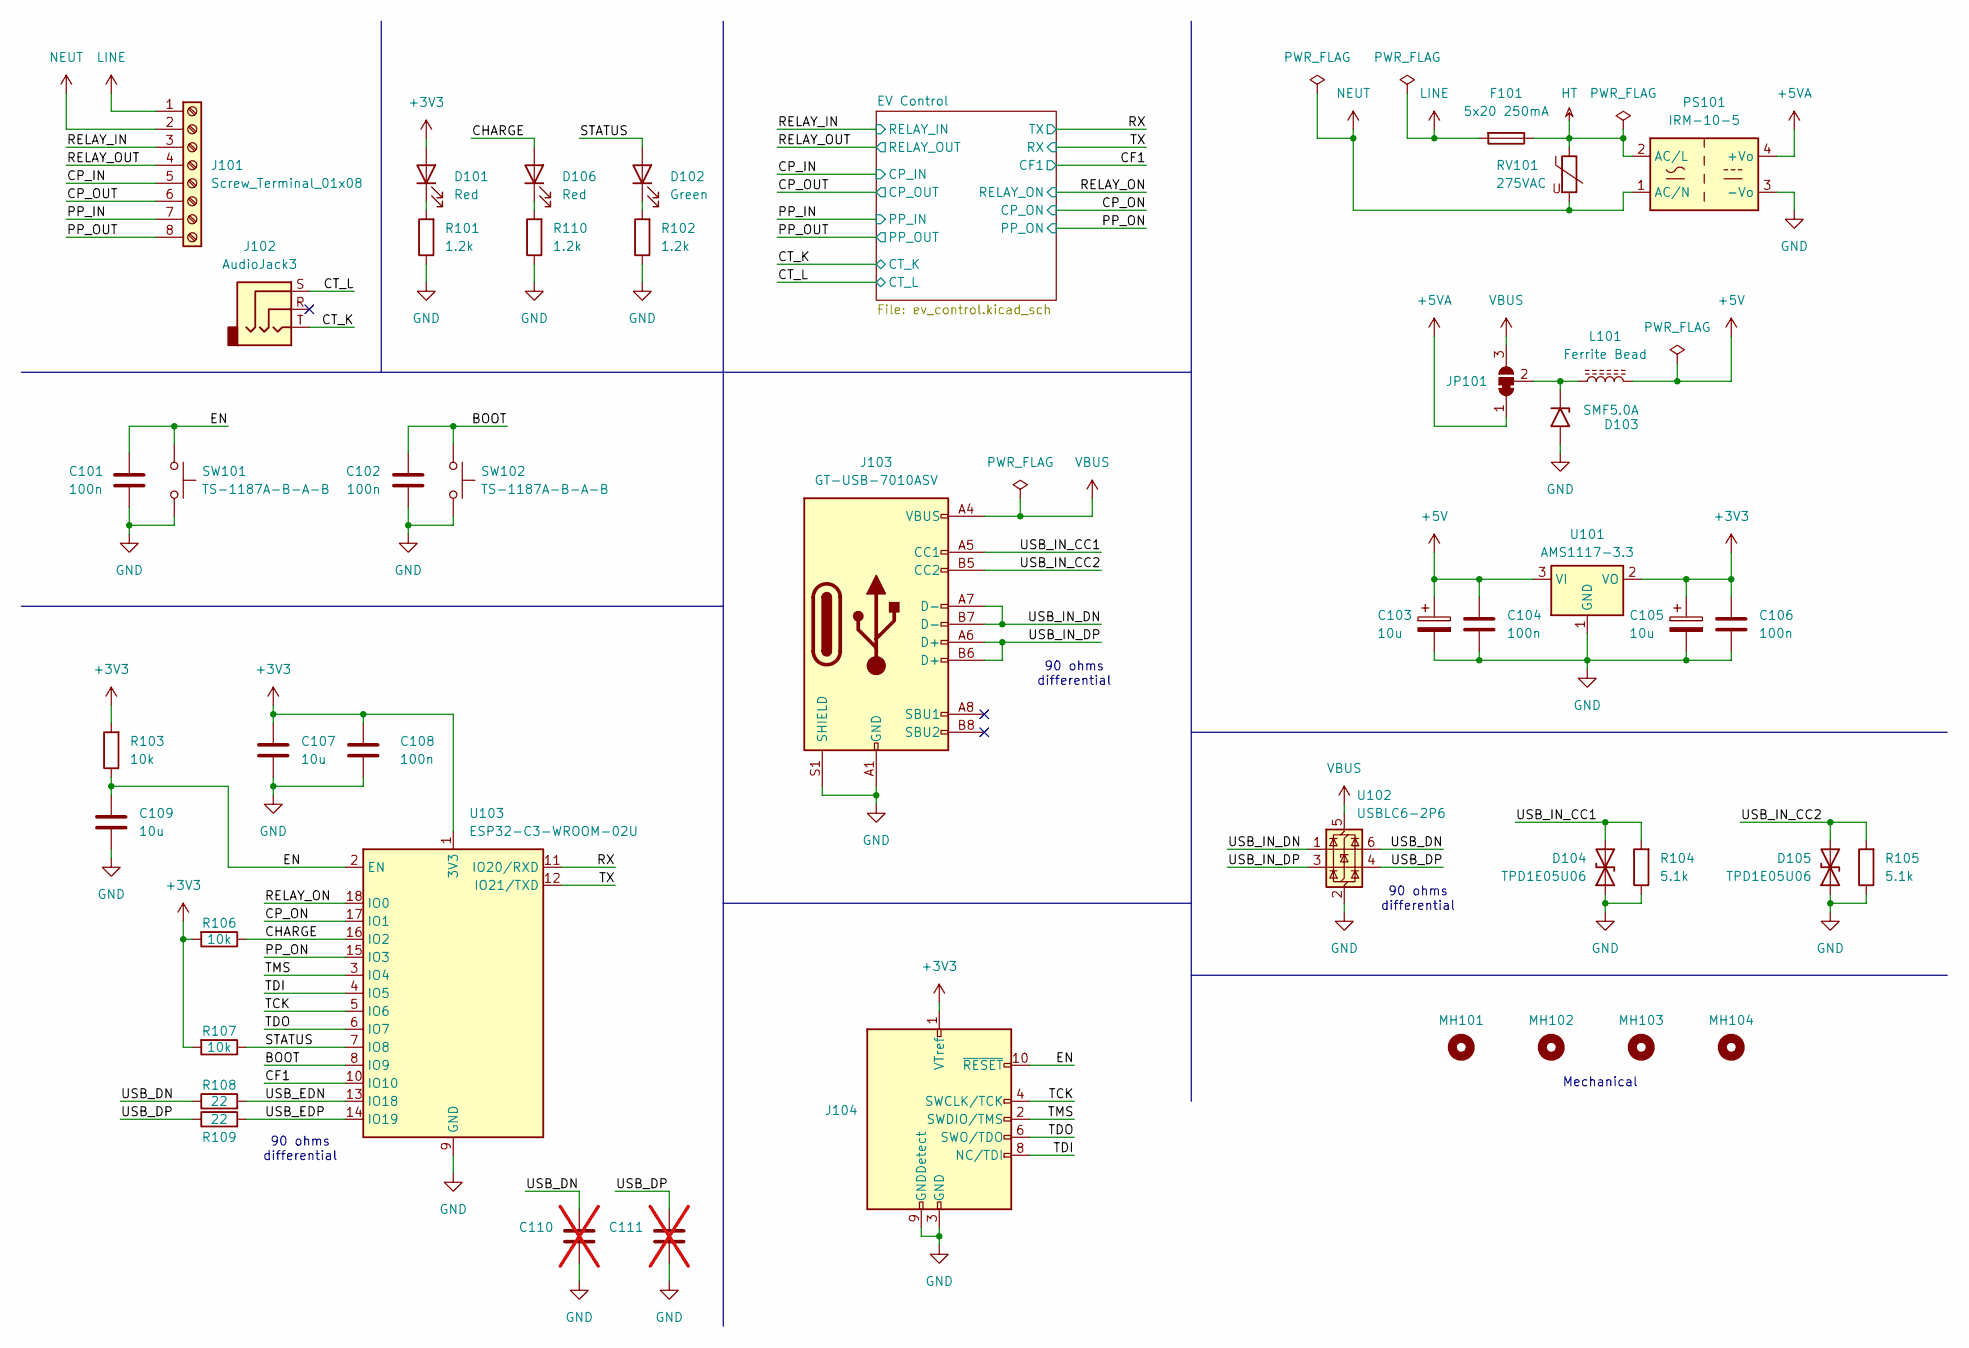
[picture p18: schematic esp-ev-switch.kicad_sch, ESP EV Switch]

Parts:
C101, C102, C108: 100n; C_0402_1005Metric; MFR Part # CL05B104KO5NNNC; LCSC Part # C1525
C103, C105: 10u; CP_EIA-3216-18_Kemet-A; MFR Part # TAJA106K016RNJ; LCSC Part # C7171
C104, C106: 100n; C_0603_1608Metric; MFR Part # CC0603KRX7R9BB104; LCSC Part # C14663
C107, C109: 10u; C_0603_1608Metric; MFR Part # CL10A106MA8NRNC; LCSC Part # C96446
C110, C111: C_0402_1005Metric; not fitted
D101, D106: Red; LED_0805_2012Metric; MFR Part # NCD0805R1; LCSC Part # C84256
D102: Green; LED_0805_2012Metric; MFR Part # KT-0805G; LCSC Part # C2297
D103: SMF5.0A; D_SOD-123F; MFR Part # SMF5.0A; LCSC Part # C19077497
D104, D105: TPD1E05U06; Texas_DPY0002A_0.6x1mm_P0.65mm; MFR Part # TPD1E05U06DPYR; LCSC Part # C436349
F101: 5x20 250mA; Littelfuse_05200101Z; MFR Part # 05200101Z; LCSC Part # C142924
J101: Screw_Terminal_01x08; TerminalBlock_WAGO_236-408_1x08_P5.00mm_45Degree; MFR Part # 236-408; LCSC Part # C3820284
J102: AudioJack3; Jack_3.5mm_PJ320D_Horizontal; MFR Part # PJ-320D; LCSC Part # C431535
J103: GT-USB-7010ASV; USB_C_Receptacle_G-Switch_GT-USB-7010ASV; MFR Part # GT-USB-7010ASV; LCSC Part # C2988369
J104: Conn_ARM_JTAG_SWD_10; PinHeader_2x05_P1.27mm_Vertical_SMD; MFR Part # HX PZ1.27-2x5P TP; LCSC Part # C41376037
JP101: SolderJumper_3_Bridged12; SolderJumper-3_P1.3mm_Bridged2Bar12_RoundedPad1.0x1.5mm
L101: Ferrite Bead; L_0603_1608Metric; MFR Part # BLM18PG121SN1D; LCSC Part # C14709
MH101, MH102, MH103, MH104: MountingHole_2.7mm_M2.5_ISO7380
PS101: IRM-10-5; Converter_ACDC_MeanWell_IRM-10-xx_THT; MFR Part # IRM-10-5; LCSC Part # C2857903
R101, R102, R110: 1.2k; R_0402_1005Metric; MFR Part # 0402WGF1201TCE; LCSC Part # C25862
R103, R106, R107: 10k; R_0402_1005Metric; MFR Part # 0402WGF1002TCE; LCSC Part # C25744
R104, R105: 5.1k; R_0402_1005Metric; MFR Part # 0402WGF5101TCE; LCSC Part # C25905
R108, R109: 22; R_0402_1005Metric; MFR Part # 0402WGF220JTCE; LCSC Part # C25092
RV101: 275VAC; RV_Disc_D12mm_W5.4mm_P7.5mm; MFR Part # 10D471K; LCSC Part # C8760
SW101, SW102: TS-1187A-B-A-B; SW_Push_1P1T_XKB_TS-1187A; MFR Part # TS-1187A-B-A-B; LCSC Part # C318884
U101: AMS1117-3.3; SOT-223-3_TabPin2; MFR Part # AMS1117-3.3; LCSC Part # C6186
U102: USBLC6-2P6; SOT-666; MFR Part # USBLC6-2P6; LCSC Part # C15999
U103: ESP32-C3-WROOM-02U; MFR Part # ESP32-C3-WROOM-02U-N4; LCSC Part # C2926676

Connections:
+3V3: C105.1, C106.1, C107.1, C108.2, D101.2 (A), J104.1 (VTref), R103.2, R106.2, R107.2, U101.2 (VO), U103.1 (3V3); also elsewhere on the board
+5V: C103.1, C104.1, L101.2, U101.3 (VI); also elsewhere on the board
+5VA: JP101.1 (A), PS101.4 (+Vo)
/BOOT: C102.1, SW102.1, U103.8 (IO9)
/CF1: U103.10 (IO10); also elsewhere on the board
/CHARGE: D106.2 (A), R106.1, U103.16 (IO2)
/CP_IN: J101.5; also elsewhere on the board
/CP_ON: U103.17 (IO1); also elsewhere on the board
/CP_OUT: J101.6; also elsewhere on the board
/CT_K: J102.T; also elsewhere on the board
/CT_L: J102.S; also elsewhere on the board
/EN: C101.1, C109.1, J104.10 (~RESET), R103.1, SW101.1, U103.2 (EN)
/PP_IN: J101.7; also elsewhere on the board
/PP_ON: U103.15 (IO3); also elsewhere on the board
/PP_OUT: J101.8; also elsewhere on the board
/RELAY_IN: J101.3; also elsewhere on the board
/RELAY_ON: U103.18 (IO0); also elsewhere on the board
/RELAY_OUT: J101.4; also elsewhere on the board
/RX: U103.11 (IO20/RXD); also elsewhere on the board
/STATUS: D102.2 (A), R107.1, U103.7 (IO8)
/TCK: J104.4 (SWCLK/TCK), U103.5 (IO6)
/TDI: J104.8 (NC/TDI), U103.4 (IO5)
/TDO: J104.6 (SWO/TDO), U103.6 (IO7)
/TMS: J104.2 (SWDIO/TMS), U103.3 (IO4)
/TX: U103.12 (IO21/TXD); also elsewhere on the board
/USB_DN: C110.1, R108.1, U102.6 (I/O1)
/USB_DP: C111.1, R109.1, U102.4 (I/O2)
/USB_EDN: R108.2, U103.13 (IO18)
/USB_EDP: R109.2, U103.14 (IO19)
/USB_IN_CC1: D104.2 (A2), J103.A5 (CC1), R104.2
/USB_IN_CC2: D105.2 (A2), J103.B5 (CC2), R105.2
/USB_IN_DN: J103.A7 (D-), J103.B7 (D-), U102.1 (I/O1)
/USB_IN_DP: J103.A6 (D+), J103.B6 (D+), U102.3 (I/O2)
GND: C101.2, C102.2, C103.2, C104.2, C105.2, C106.2, C107.2, C108.1, C109.2, C110.2, C111.2, D103.2 (A2), D104.1 (A1), D105.1 (A1), J103.A1 (GND), J103.A12 (GND), J103.B1 (GND), J103.B12 (GND), J103.S1 (SHIELD), J104.3 (GND), J104.5 (GND), J104.9 (GNDDetect), PS101.3 (-Vo), R101.1, R102.1, R104.1, R105.1, R110.1, SW101.2, SW102.2, U101.1 (GND), U102.2 (GND), U103.9 (GND), U103.19 (GND); also elsewhere on the board
HT: F101.1, PS101.2 (AC/L), RV101.1; also elsewhere on the board
LINE: F101.2, J101.1
NEUT: J101.2, PS101.1 (AC/N), RV101.2; also elsewhere on the board
unnamed: D101.1 (K), R101.2
unnamed: D102.1 (K), R102.2
unnamed: D103.1 (A1), JP101.2 (C), L101.1
unnamed: D106.1 (K), R110.2
VBUS: J103.A4 (VBUS), J103.A9 (VBUS), J103.B4 (VBUS), J103.B9 (VBUS), JP101.3 (B), U102.5 (VBUS)

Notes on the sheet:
90 ohms differential
Mechanical

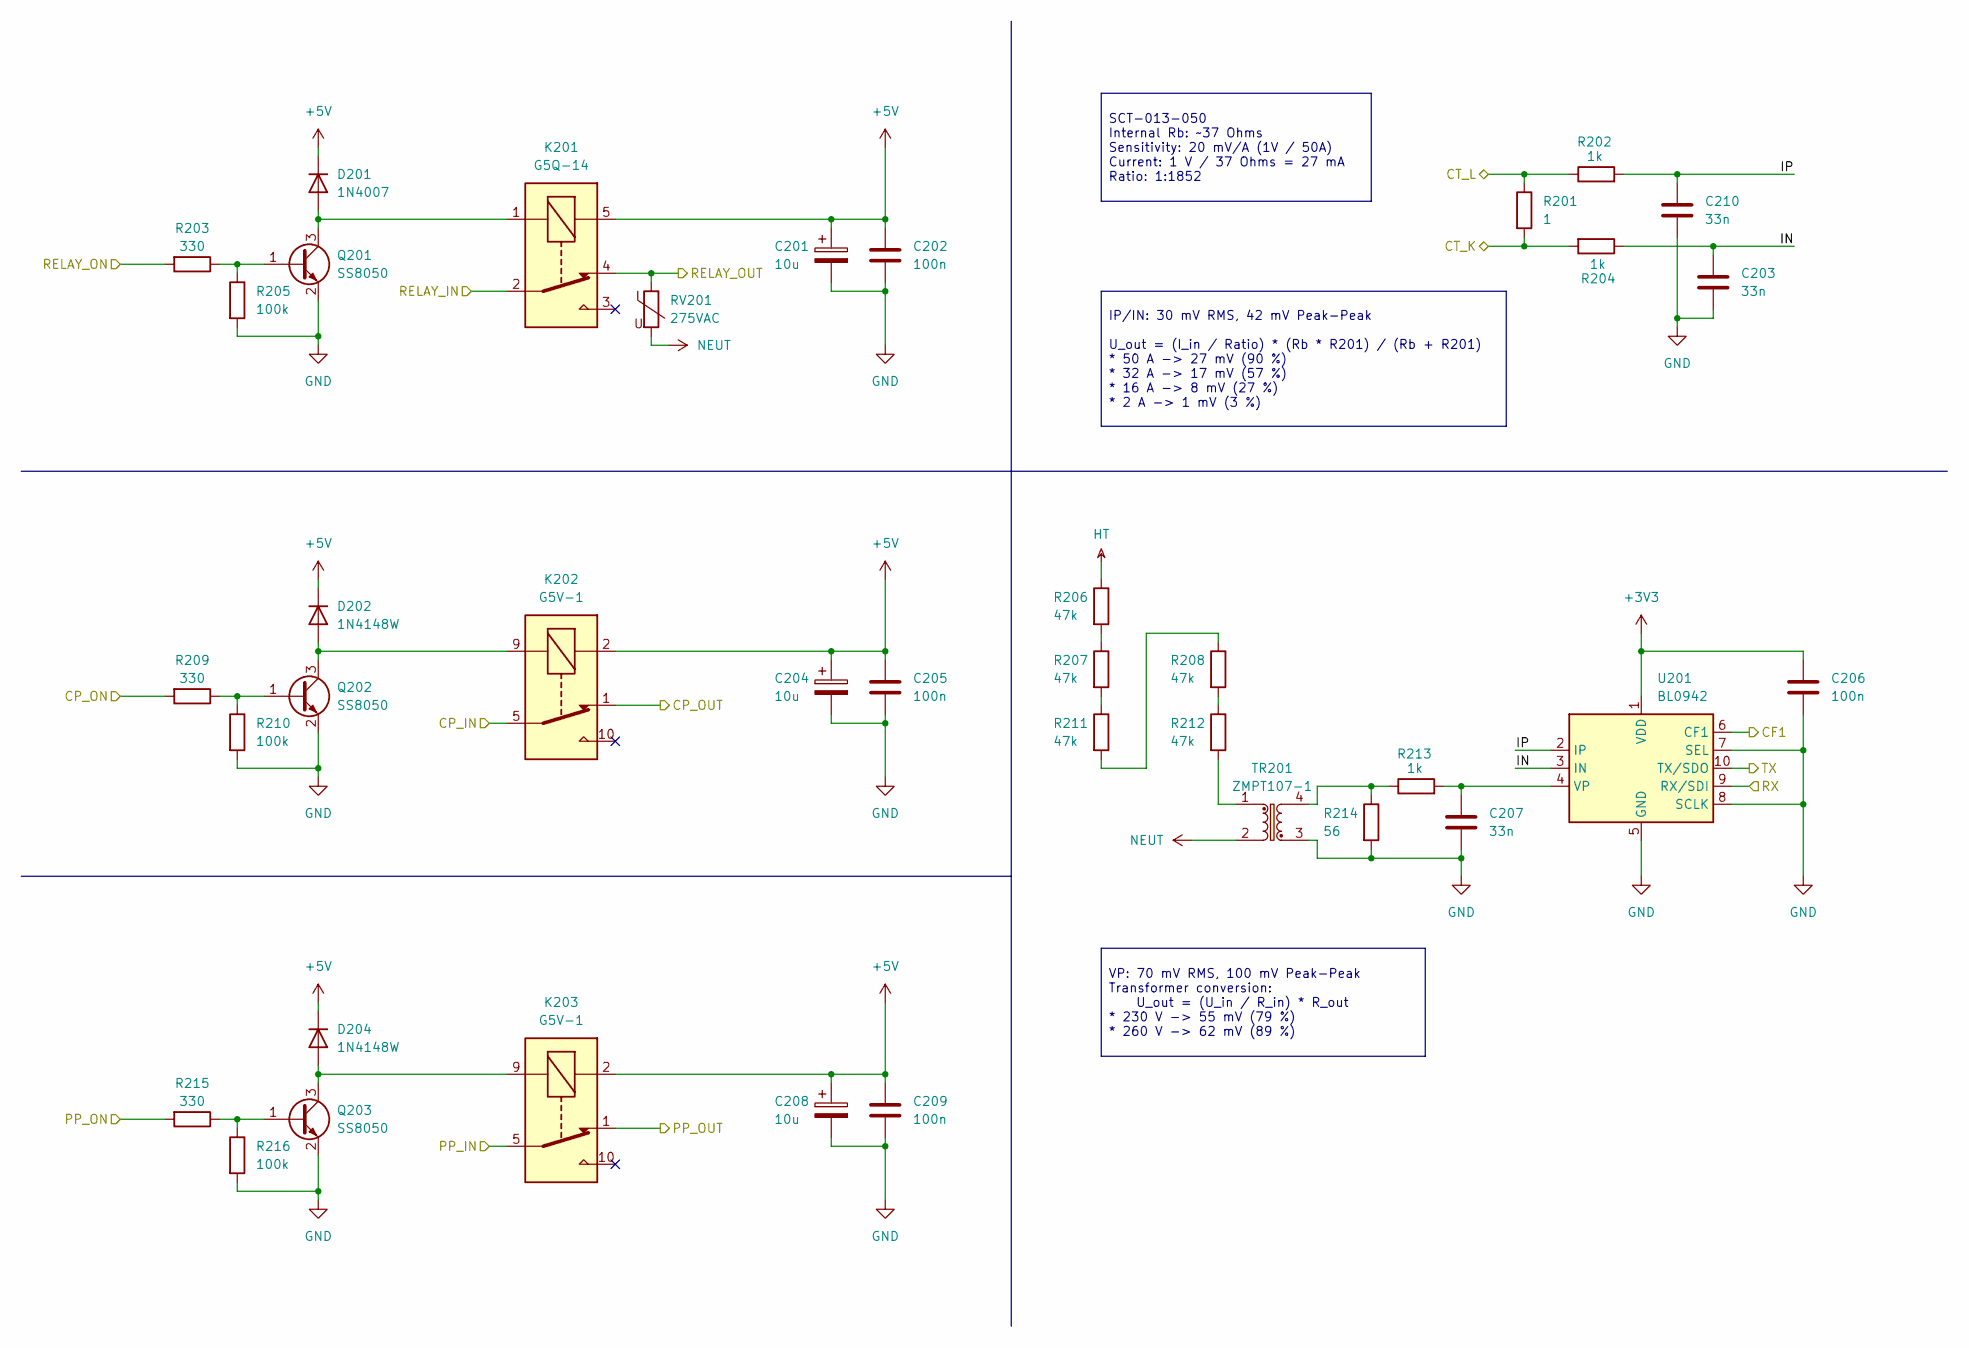
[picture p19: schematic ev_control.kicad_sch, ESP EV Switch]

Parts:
C201, C204, C208: 10u; CP_EIA-3216-18_Kemet-A; MFR Part # TAJA106K016RNJ; LCSC Part # C7171
C202, C205, C206, C209: 100n; C_0603_1608Metric; MFR Part # CC0603KRX7R9BB104; LCSC Part # C14663
C203, C207, C210: 33n; C_0603_1608Metric; MFR Part # CL10B333KB8NNNC; LCSC Part # C21117
D201: 1N4007; D_SOD-123F; MFR Part # 1N4007W; LCSC Part # C18199088
D202, D204: 1N4148W; D_SOD-123; MFR Part # 1N4148W; LCSC Part # C7420318
K201: G5Q-14; Relay_SPDT_Omron-G5Q-1; MFR Part # G5Q-14 DC5; LCSC Part # C397241
K202, K203: G5V-1; Relay_SPDT_Omron_G5V-1; MFR Part # G5V-1 DC5; LCSC Part # C28695
Q201, Q202, Q203: SS8050; SOT-23; MFR Part # SS8050(RANGE:200-350); LCSC Part # C2150
R201: 1; R_0603_1608Metric; MFR Part # 0603WAF100KT5E; LCSC Part # C22936
R202, R204, R213: 1k; R_0603_1608Metric; MFR Part # 0603WAF1001T5E; LCSC Part # C21190
R203, R209, R215: 330; R_0402_1005Metric; MFR Part # 0402WGF3300TCE; LCSC Part # C25104
R205, R210, R216: 100k; R_0402_1005Metric; MFR Part # 0402WGF1003TCE; LCSC Part # C25741
R206, R207, R208, R211, R212: 47k; R_0805_2012Metric; MFR Part # 0805W8F4702T5E; LCSC Part # C17713
R214: 56; R_0603_1608Metric; MFR Part # 0603WAF560JT5E; LCSC Part # C25196
RV201: 275VAC; RV_Disc_D12mm_W5.4mm_P7.5mm; MFR Part # 10D471K; LCSC Part # C8760
TR201: ZMPT107-1; XFMR-TH_ZMPT107-1; MFR Part # ZMPT107-1; LCSC Part # C125191
U201: BL0942; SSOP-10_3.9x4.9mm_P1.00mm; MFR Part # BL0942; LCSC Part # C2837510

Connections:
+3V3: C206.1, U201.1 (VDD); also elsewhere on the board
+5V: C201.1, C202.1, C204.1, C205.1, C208.1, C209.1, D201.1 (K), D202.1 (K), D204.1 (K), K201.5, K202.2, K203.2; also elsewhere on the board
/CF1: U201.6 (CF1); also elsewhere on the board
/CP_IN: K202.5, K202.6; also elsewhere on the board
/CP_ON: R209.2; also elsewhere on the board
/CP_OUT: K202.1; also elsewhere on the board
/CT_K: R201.2, R204.2; also elsewhere on the board
/CT_L: R201.1, R202.1; also elsewhere on the board
/EV Control/IN: C203.1, R204.1, U201.3 (IN)
/EV Control/IP: C210.1, R202.2, U201.2 (IP)
/PP_IN: K203.5, K203.6; also elsewhere on the board
/PP_ON: R215.2; also elsewhere on the board
/PP_OUT: K203.1; also elsewhere on the board
/RELAY_IN: K201.2; also elsewhere on the board
/RELAY_ON: R203.2; also elsewhere on the board
/RELAY_OUT: K201.4, RV201.1; also elsewhere on the board
/RX: U201.10 (TX/SDO); also elsewhere on the board
/TX: U201.9 (RX/SDI); also elsewhere on the board
GND: C201.2, C202.2, C203.2, C204.2, C205.2, C206.2, C207.2, C208.2, C209.2, C210.2, Q201.2 (E), Q202.2 (E), Q203.2 (E), R205.2, R210.2, R214.2, R216.2, TR201.3, U201.5 (GND), U201.7 (SEL), U201.8 (SCLK); also elsewhere on the board
HT: R206.1; also elsewhere on the board
NEUT: RV201.2, TR201.2; also elsewhere on the board
unnamed: D201.2 (A), K201.1, Q201.3 (C)
unnamed: D202.2 (A), K202.9, Q202.3 (C)
unnamed: D204.2 (A), K203.9, Q203.3 (C)
unnamed: Q201.1 (B), R203.1, R205.1
unnamed: Q202.1 (B), R209.1, R210.1
unnamed: Q203.1 (B), R215.1, R216.1
unnamed: R206.2, R207.1
unnamed: R207.2, R211.1
unnamed: R208.1, R211.2
unnamed: R208.2, R212.1
unnamed: R212.2, TR201.1
unnamed: R213.1, R214.1, TR201.4
unnamed: C207.1, R213.2, U201.4 (VP)

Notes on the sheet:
SCT-013-050 Internal Rb: ~37 Ohms Sensitivity: 20 mV/A (1V / 50A) Current: 1 V / 37 Ohms = 27 mA Ratio: 1:1852
VP: 70 mV RMS, 100 mV Peak-Peak Transformer conversion: U_out = (U_in / R_in) * R_out * 230 V -> 55 mV (79 %) * 260 V -> 62 mV (89 %)
IP/IN: 30 mV RMS, 42 mV Peak-Peak U_out = (I_in / Ratio) * (Rb * R201) / (Rb + R201) * 50 A -> 27 mV (90 %) * 32 A -> 17 mV (57 %) * 16 A -> 8 mV (27 %) * 2 A -> 1 mV (3 %)

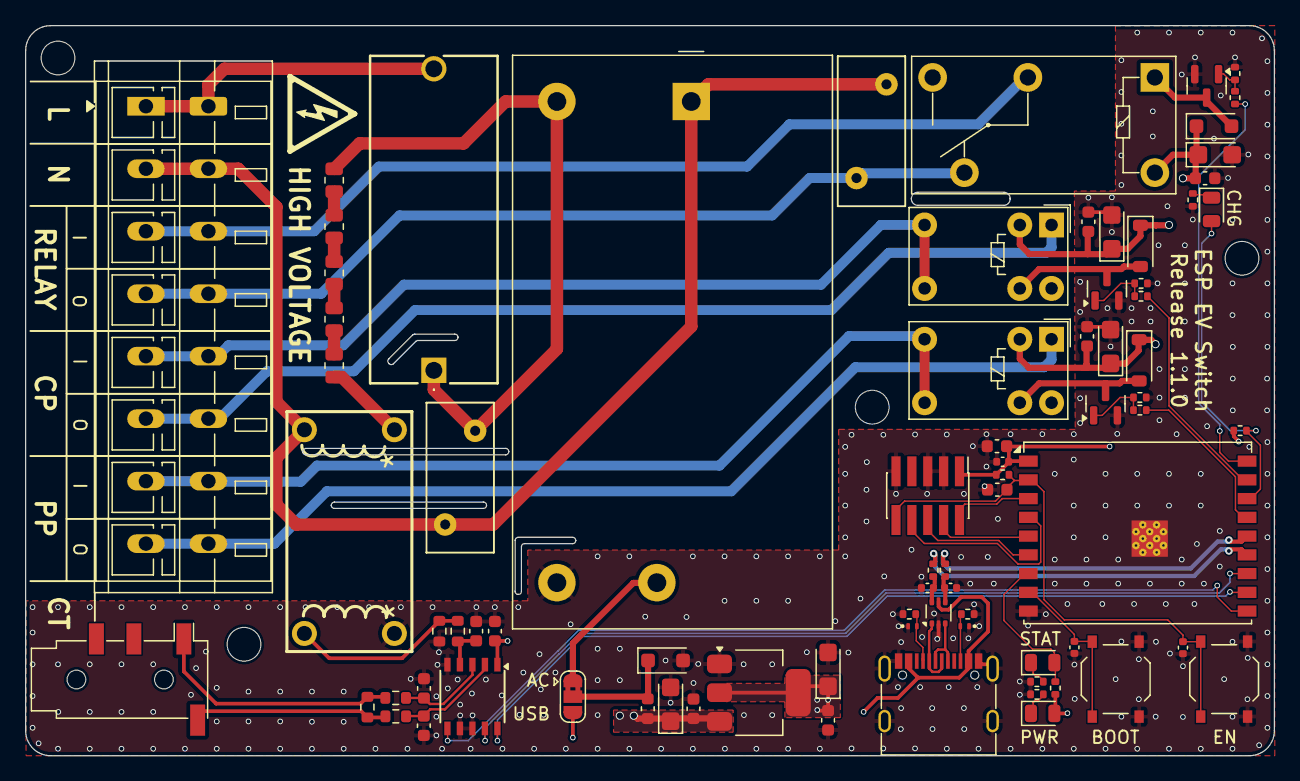
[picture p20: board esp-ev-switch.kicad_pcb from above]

Board: 4 copper layers, 99.9 x 58.4 mm, 83 parts (0 on the bottom side), 57 nets.

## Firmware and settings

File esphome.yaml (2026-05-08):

substitutions:
  hostname: ev-switch
  entity_name: EV Switch
  voltage_ref: 14400
  current_ref: 111500
  ev_delay_ms: 15000

esphome:
  name: ${hostname}
  comment: EV Switch
  project:
    name: valletw.esp-ev-switch
    version: 1.1.0

esp32:
  variant: esp32c3
  flash_size: 4MB
  framework:
    type: esp-idf
    version: recommended

wifi:
  ssid: !secret wifi_ssid
  password: !secret wifi_password
  output_power: 17dB
  fast_connect: On
  ap:
    ssid: !secret wifi_fb_ssid
    password: !secret wifi_fb_password

captive_portal:

ota:
  - platform: esphome
    password: !secret ota_password

api:
  encryption:
    key: !secret api_key

logger:
  level: DEBUG

globals:
  - id: last_toggle_time
    type: unsigned long
    restore_value: no
    initial_value: '0'

status_led:
  pin:
    number: GPIO8
    ignore_strapping_warning: true

output:
  - platform: gpio
    id: charge_status
    pin:
      number: GPIO2
      ignore_strapping_warning: true

uart:
  id: uart1_bus
  tx_pin: GPIO21
  rx_pin: GPIO20
  baud_rate: 4800
  parity: NONE
  stop_bits: 1

switch:
  - platform: gpio
    id: relay_on
    internal: true
    pin:
      number: GPIO0
      inverted: true
    restore_mode: ALWAYS_OFF

  - platform: gpio
    id: cp_on
    internal: true
    pin:
      number: GPIO1
      inverted: true
    restore_mode: ALWAYS_OFF

  - platform: gpio
    id: pp_on
    internal: true
    pin:
      number: GPIO3
      inverted: true
    restore_mode: ALWAYS_OFF

  - platform: template
    name: ${entity_name} Activate
    icon: mdi:ev-station
    lambda: return id(relay_on).state;
    turn_on_action:
      - script.execute: ev_start
    turn_off_action:
      - script.execute: ev_stop

sensor:
  - platform: wifi_signal
    name: "WiFi RSSI"
    update_interval: 60s

  - platform: bl0942
    uart_id: uart1_bus
    update_interval: 15s
    current:
      name: ${entity_name} Current
      accuracy_decimals: 2
    voltage:
      name: ${entity_name} Voltage
      accuracy_decimals: 2
    power:
      name: ${entity_name} Power
      accuracy_decimals: 2
      filters:
        - lambda: |-
            if (x < 1) return 0;
            return x;
    energy:
      name: ${entity_name} Energy
      accuracy_decimals: 2
    frequency:
      name: ${entity_name} Frequency
      accuracy_decimals: 2
    voltage_reference: ${voltage_ref}
    current_reference: ${current_ref}

button:
  - platform: restart
    name: Restart controller

script:
  - id: ev_start
    mode: single
    then:
      - if:
          condition:
            lambda: |
              return !id(ev_stop).is_running()
                  && (millis() - id(last_toggle_time)) >= ${ev_delay_ms};
          then:
            - lambda: id(last_toggle_time) = millis();
            - logger.log: "EV start"
            - output.turn_on: charge_status
            - switch.turn_on: relay_on
            - delay: 300ms
            - switch.turn_on: cp_on
            - delay: 200ms
            - switch.turn_on: pp_on
            - logger.log: "EV ON"
          else:
            - lambda: |
                if (id(ev_stop).is_running()) {
                  ESP_LOGW("EV", "EV stop on going, skipped");
                } else {
                  ESP_LOGW("EV", "Security delay, start skipped");
                }

  - id: ev_stop
    mode: single
    then:
      - if:
          condition:
            lambda: |
              return !id(ev_start).is_running()
                  && (millis() - id(last_toggle_time)) >= ${ev_delay_ms};
          then:
            - lambda: id(last_toggle_time) = millis();
            - logger.log: "EV stop"
            - switch.turn_off: pp_on
            - delay: 5s
            - switch.turn_off: cp_on
            - delay: 1s
            - switch.turn_off: relay_on
            - output.turn_off: charge_status
            - logger.log: "EV OFF"
          else:
            - lambda: |
                if (id(ev_start).is_running()) {
                  ESP_LOGW("EV", "EV start on going, skipped");
                } else {
                  ESP_LOGW("EV", "Security delay, stop skipped");
                }

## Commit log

2025-11-12 Add Kicad project
    [G5Q-14_DC5.step, IRM-10-5.stp, Littelfuse_05200101Z.stp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]
2025-11-12 Add Kicad export files: schematic, BOM, Gerber
    [bom.csv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]
2025-12-04 Invert relay logic on ESPHome configuration
    [esphome.yaml]
2025-12-05 Update configuration after calibration
2026-03-28 Fix EV start/stop sequence
    [esphome.yaml]
2026-04-13 Change BL0942 probing system
    - Add isolation on VP
    - Modify IN/IP setup without 3V3
    [XFMR-TH_L19.0-W10.0-H18.2.step, bom.csv, designators.csv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]
2026-04-13 Fix JLCPCB positions file
    [cpl.csv]
2026-05-08 Update calibration information
2026-05-08 Update board image

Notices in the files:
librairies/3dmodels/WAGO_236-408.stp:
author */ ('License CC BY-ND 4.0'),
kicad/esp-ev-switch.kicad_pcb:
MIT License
